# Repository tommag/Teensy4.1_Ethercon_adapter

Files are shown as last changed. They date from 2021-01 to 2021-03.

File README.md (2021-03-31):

# Teensy 4.1 etherCON adapter

These are the design files to add a Neutrik etherCON Ethernet connector to your Teensy 4.1. It replaces the official [Ethernet kit for Teensy 4.1](https://www.pjrc.com/store/ethernet_kit.html) sold by PJRC and provides a panel-mountable, rugged Ethernet port to your Teensy.

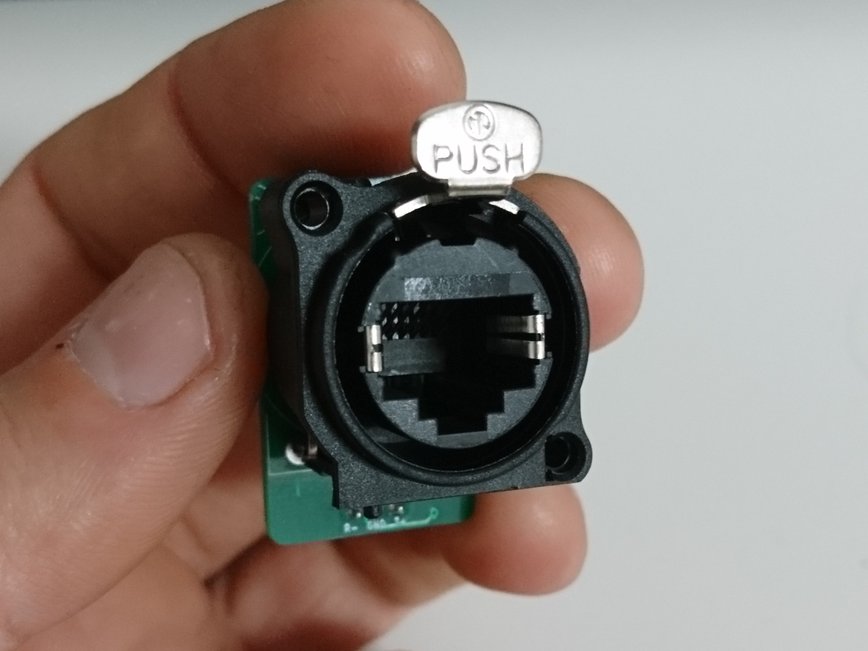
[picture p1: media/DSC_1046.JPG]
Connector


## Get the PCB made

Order from OSHPark here : https://oshpark.com/shared_projects/l8queh8X

Or you can get the PCB made by the board house of your choice, just send them the .zip file in the `gerber` directory.

## Bill of materials

| Designator  | Qty | Value | Package | Farnell P/N | Mouser P/N | Digikey P/N |
|---|---|---|---|---|---|---|
| C1 |  1  | 0.1uF/50V  | C_0805_2012Metric | 3013478 | 581-08055C104K | 1276-1003-1-ND |
| C2 |  1  | 1000pF/2kV | C_0805_2012Metric |	2522440	 |	791-0805B102K102CT|	311-4341-1-ND |
| D1 |  1  | LED | LED_1206_3216Metric						 | | | |
| J1 |  2  | Conn_01x06 | PinHeader_2x03_P2mm_Vertical						 | | | |
| J2 |  1  | NE8FAV | Neutrik_EtherCON_NE8FAV_1x8P_GND_Female_Vertical	| 1202031	 |	568-NE8FAV | |
| R4,R3,R2,R1 |  4  | 75R | R_0805_2012Metric | 2671086	 |	652-CR0805JW-750ELF| RR12Q75DCT-ND |
| TR1 |  1  | PT61017PEL | Transformer_Ethernet_Bourns_PT61017PEL | | 652-PT61017PEL |	PT61017PELCT-ND |

You will also need **1mm pitch** 6 conductors ribbon cable and 2 **2mm pitch** female IDC connectors to connect the Teensy and the etherCON adapter. 

## Assembly steps
Check out the html interactive BoM in the `bom` directory.

1. Solder the passive components. You don't need a stencil and solder paste, a soldering iron with fine tip is OK.

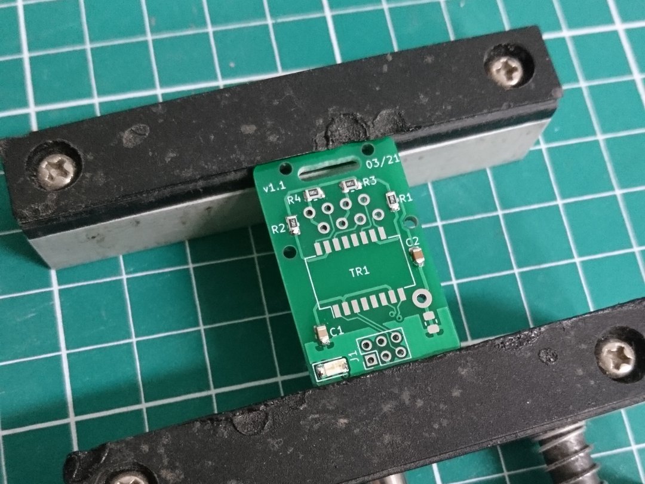
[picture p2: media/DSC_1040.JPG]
Soldering passives


2. Solder the LAN magnetics. 

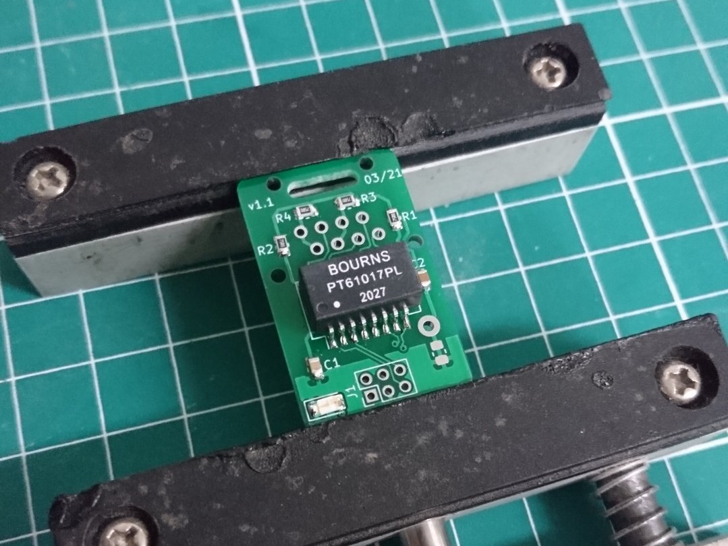
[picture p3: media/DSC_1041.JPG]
Soldering LAN mag


3. Solder the 2mm pin header and the etherCON jack

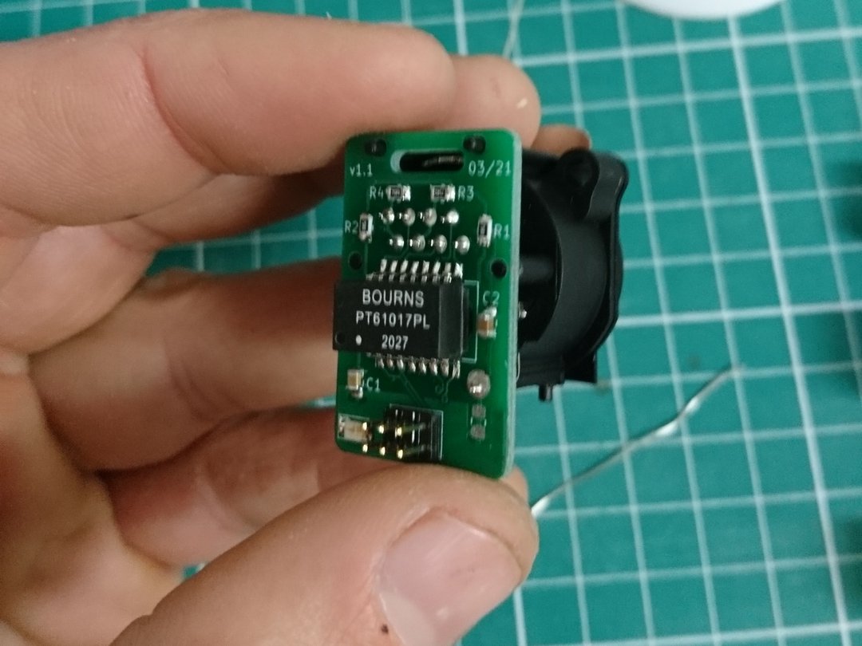
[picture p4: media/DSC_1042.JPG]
Soldering through hole components


4. Solder a 2mm pin header to your Teensy 4.1

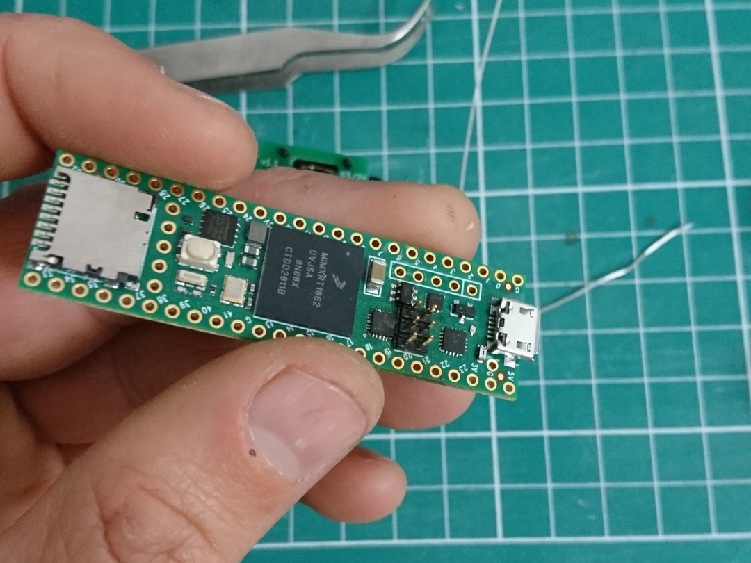
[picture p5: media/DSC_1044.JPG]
Soldering pin header to Teensy


5. Connect the etherCON adapter to the Teensy with a ribbon cable (pay attention to the connector orientation)

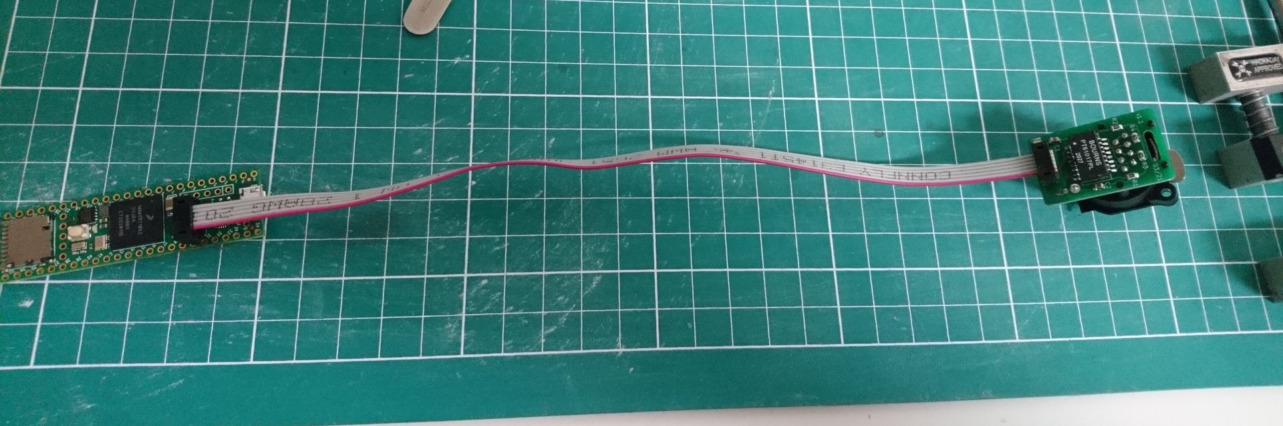
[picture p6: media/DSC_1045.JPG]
Connected with a ribbon cable


Just like the Ethernet kit, you need to use the `NativeEthernet` library to use the integrated Ethernet port.

On the bottom right of the PCB, you can see an unused 0805 footprint (R5 in the design files). If you need (and you know better than me), you can cut the trace under the footprint and handle differently the Ethernet grounding.

6. Enjoy a panel mount, professionnal-looking Ethernet port for your Teensy!

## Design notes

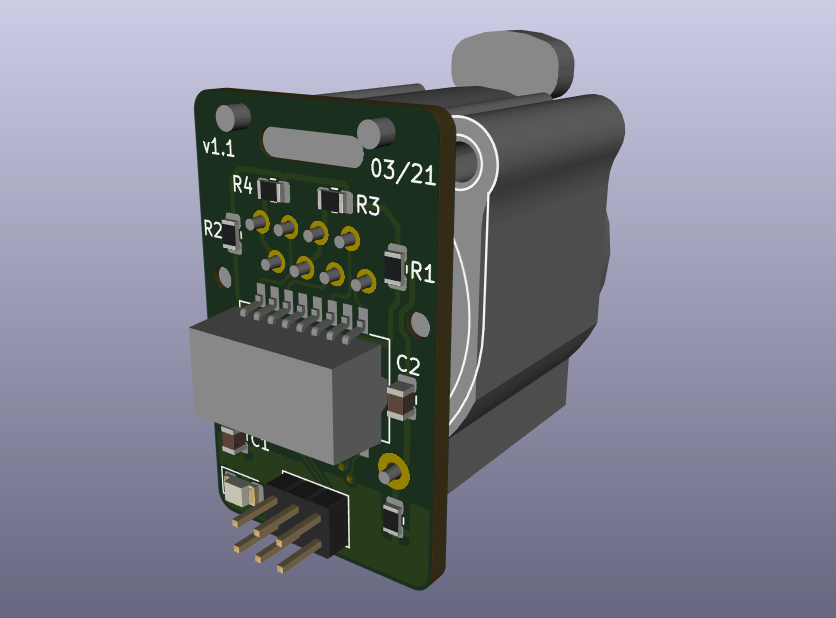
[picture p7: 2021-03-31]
Teensy4.1_Ethercon_adapter.png

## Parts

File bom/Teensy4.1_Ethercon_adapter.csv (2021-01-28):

Id | Référence | Boîtier | Quantité | Désignation | Fournisseur et réf
1 | D1 | LED_1206_3216Metric | 1 | LED
2 | C1 | C_0805_2012Metric | 1 | 0.1uF/50V
3 | R4,R3,R2,R1 | R_0805_2012Metric | 4 | 75R
4 | C2 | C_0805_2012Metric | 1 | 1000pF/2kV
5 | J2 | Neutrik_EtherCON_NE8FAV_1x8P_GND_Female_Vertical | 1 | NE8FAV
6 | TR1 | Transformer_Ethernet_Bourns_PT61017PEL | 1 | PT61017PEL
7 | J1 | PinHeader_2x03_P2.54mm_Vertical | 1 | Conn_01x06

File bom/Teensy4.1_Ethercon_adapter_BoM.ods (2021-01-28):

Teensy 4.1 Ethercon adapter
v1.0 – 01/2021
Designator | Qty | Value | Package | Farnell P/N | Farnell price | Mouser P/N | Mouser price | Digikey P/N | Digikey price
C1 | 1 | 0.1uF/50V | C_0805_2012Metric | 3013478 | 0,03 | 581-08055C104K | 0,085 | 1276-1003-1-ND | 0,08
C2 | 1 | 1000pF/2kV | C_0805_2012Metric | 2522440 | 0,246 | 791-0805B102K102CT | 0,184 | 311-4341-1-ND (https://www.digikey.fr/product-detail/fr/yageo/CC0805KRX7RCBB102/311-4341-1-ND/8025430) | 0,24
D1 | 1 | LED | LED_1206_3216Metric
J1 | 2 | Conn_01x06 | PinHeader_2x03_P2.54mm_Vertical
J2 | 1 | NE8FAV | Neutrik_EtherCON_NE8FAV_1x8P_GND_Female_Vertical | 1202031 | 4,75 | 568-NE8FAV | 4,29
R4,R3,R2,R1 | 4 | 75R | R_0805_2012Metric | 2671086 | 0,005 | 652-CR0805JW-750ELF | 0,085 | RR12Q75DCT-ND (https://www.digikey.fr/product-detail/fr/susumu/RR1220Q-750-D/RR12Q75DCT-ND/432803) | 0,08
TR1 | 1 | PT61017PEL | Transformer_Ethernet_Bourns_PT61017PEL |  |  | 652-PT61017PEL | 1,31 | PT61017PELCT-ND (https://www.digikey.fr/product-detail/fr/bourns-inc/PT61017PEL/PT61017PELCT-ND/4490533) | 1,29

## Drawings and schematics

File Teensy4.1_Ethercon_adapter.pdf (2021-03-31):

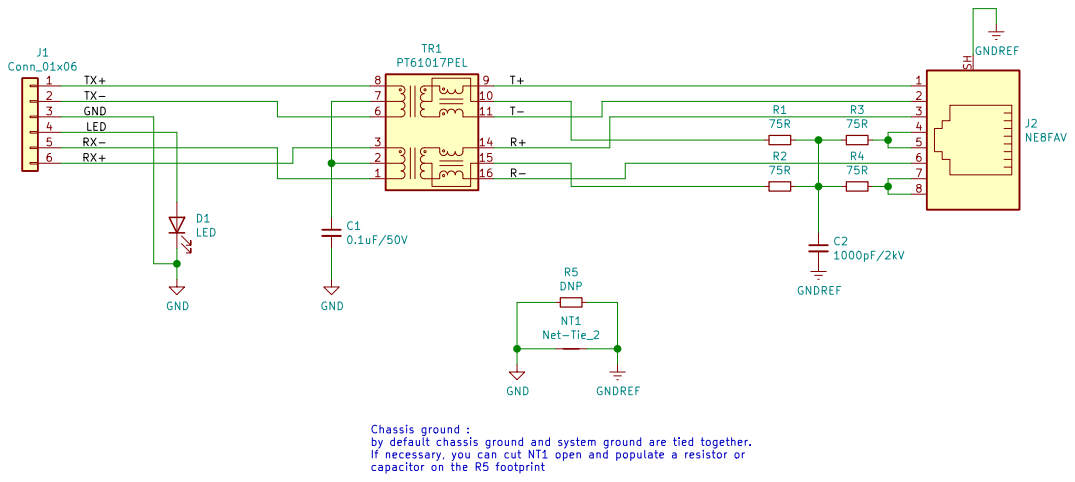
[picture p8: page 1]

File: Teensy4.1_Ethercon_adapter.sch Sheet: / Tom Magnier C1

by default chassis ground and system ground are tied together.
If necessary, you can cut NT1 open and populate a resistor or
capacitor on the R5 footprint

Id: 1/1 Title: Teensy 4.1 Ethercon adapter

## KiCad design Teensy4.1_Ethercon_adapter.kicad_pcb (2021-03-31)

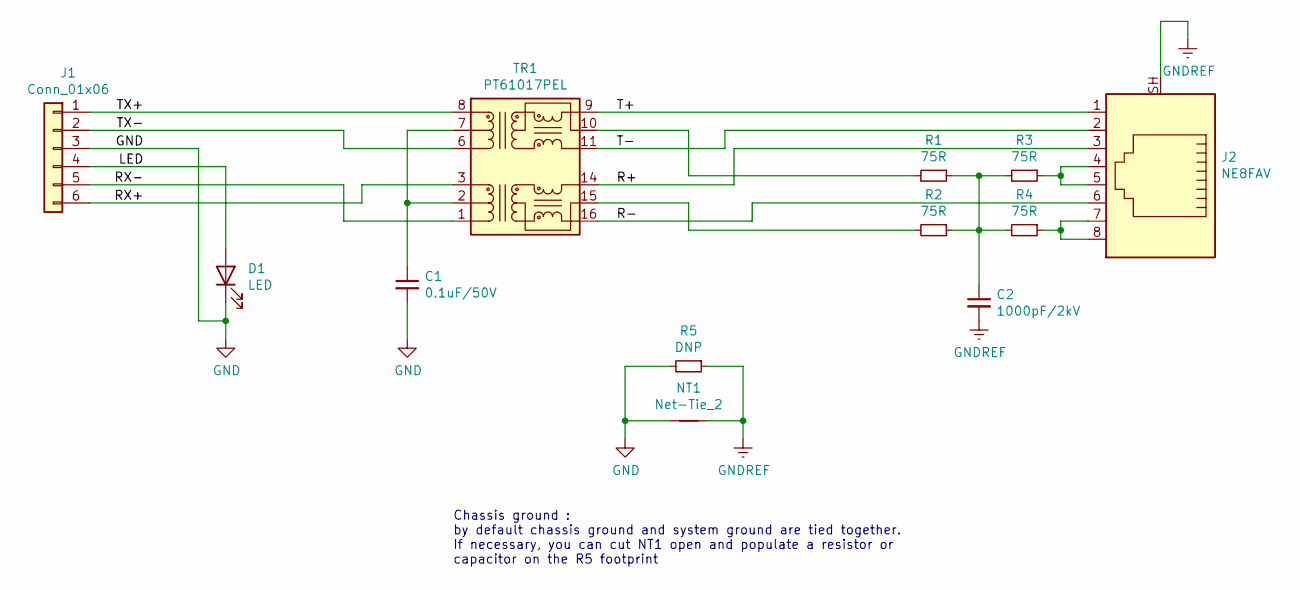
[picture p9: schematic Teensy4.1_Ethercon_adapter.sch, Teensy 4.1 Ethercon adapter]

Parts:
C1: 0.1uF/50V; C_0805_2012Metric
C2: 1000pF/2kV; C_0805_2012Metric
D1: LED; LED_1206_3216Metric
J1: Conn_01x06; PinHeader_2x03_P2.00mm_Vertical
J2: NE8FAV; Neutrik_EtherCON_NE8FAV_1x8P_GND_Female_Vertical
NT1: Net-Tie_2; NetTie-2_SMD_Pad0.5mm
R1, R2, R3, R4: 75R; R_0805_2012Metric
R5: DNP; R_0805_2012Metric
TR1: PT61017PEL; Transformer_Ethernet_Bourns_PT61017PEL

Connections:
/LED: D1.2 (A), J1.4
/R+: J2.3, TR1.14 (TX-)
/R-: J2.6, TR1.16 (TX+)
/RX+: J1.6, TR1.3 (TD-)
/RX-: J1.5, TR1.1 (TD+)
/T+: J2.1, TR1.9 (RX-)
/T-: J2.2, TR1.11 (RX+)
/TX+: J1.1, TR1.8 (RD-)
/TX-: J1.2, TR1.6 (RD+)
GND: C1.2, D1.1 (K), J1.3, NT1.1, R5.2
GNDREF: C2.2, J2.SH, NT1.2, R5.1
unnamed: C1.1, TR1.2 (C_TD), TR1.7 (C_RD)
unnamed: C2.1, R1.1, R2.1, R3.2, R4.2
unnamed: J2.4, J2.5, R3.1
unnamed: J2.7, J2.8, R4.1
unnamed: R1.2, TR1.10 (C_RX)
unnamed: R2.2, TR1.15 (C_TX)

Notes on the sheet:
Chassis ground : by default chassis ground and system ground are tied together. If necessary, you can cut NT1 open and populate a resistor or capacitor on the R5 footprint

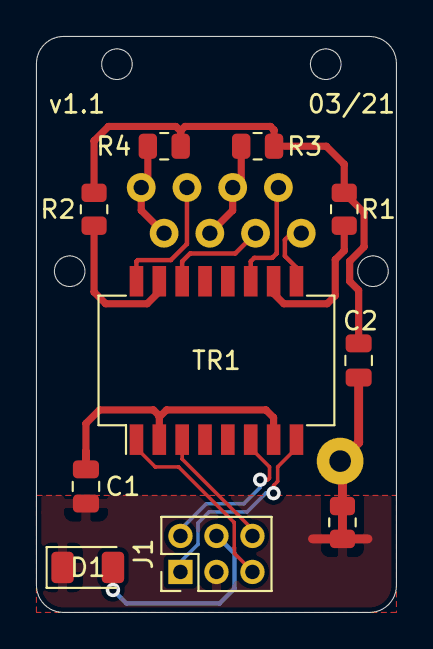
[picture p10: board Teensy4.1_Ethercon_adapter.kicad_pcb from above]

Board: 2 copper layers, 20.0 x 32.0 mm, 12 parts (1 on the bottom side), 17 nets.

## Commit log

2021-01-28 First commit v1.0
    [Teensy4.1_Ethercon_adapter-B_Cu.gbl, Teensy4.1_Ethercon_adapter-B_Mask.gbs, Teensy4.1_Ethercon_adapter-B_Paste.gbp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]
2021-03-31 Version 1.1 - fixed routing and pin header pitch (2mm)
    [Teensy4.1_Ethercon_adapter-B_Cu.gbl, Teensy4.1_Ethercon_adapter-B_Mask.gbs, Teensy4.1_Ethercon_adapter-B_Paste.gbp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]
